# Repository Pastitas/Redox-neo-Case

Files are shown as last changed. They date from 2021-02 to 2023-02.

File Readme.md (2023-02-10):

# Redox-neo keyboard Case
Redox-neo is just a case for the redox keyboard (both wireless and wired versions) based on looks and getting 'thicness' down as much as possible,  while still being 3d printable.
I also wanted to save space by using the original pcb mounting holes.
note that this should be compatible with wireless rev2 since the hole that
changes is non-essential for the case and the other 3 will work just fine

## Pics

redox_w

redox_w

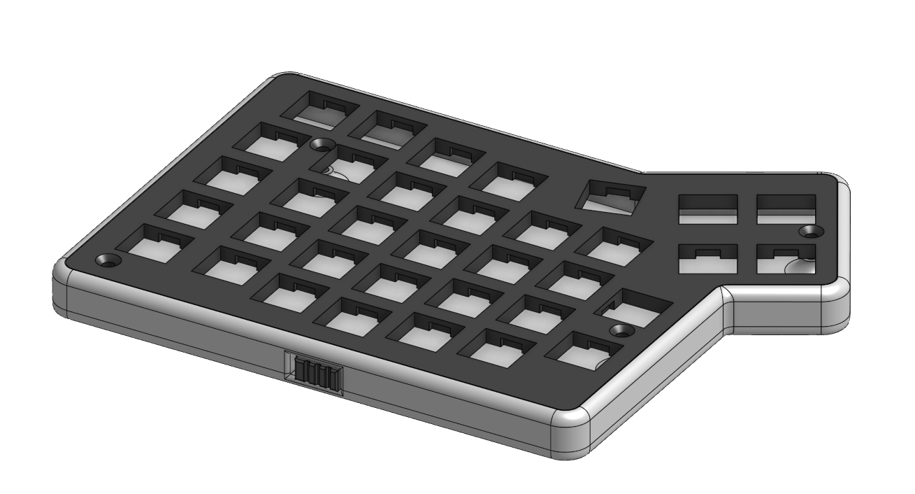
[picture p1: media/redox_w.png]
redox_w


## Usage guide
There is a calibration tester file (inside the switch_plate_tester folder) you can print with the following tolerances for the switches:
1 0.20 mm
2 0.16 mm
3 0.12 mm
4 0.08 mm

After testing your switches there you can then choose any tolerance on the stls, it's the last number in the name of the top parts

If that's not enough for your printer or want to make any changes just fork this, all files have their asociated step files WITHOUT ANY OFFSETS.

There are also testers in step format form the holes of the microcontroller and trs jacks (so you can test fit before printing and wasting plastic and time) and the alignment of the switches in the redox_w

## Screws

M3x10 screws x8 should work well without inserts.

2.5 inserts also work, but you might have to drill a bit of the holes for them to fit in (drill in reverse so you dont overdrill)

 ## Wrist Rest
by user [idaho777](https://github.com/idaho777)

I've created a set of wrist rests that maintain both dimensions and style of the original case.  These have a curved slope from the top to the bottom since that's the feeling i'm used to.

The images below are printed with layer height 0.28mm and 10% infill.
Top View            |  Side View
:-------------------------:|:-------------------------:
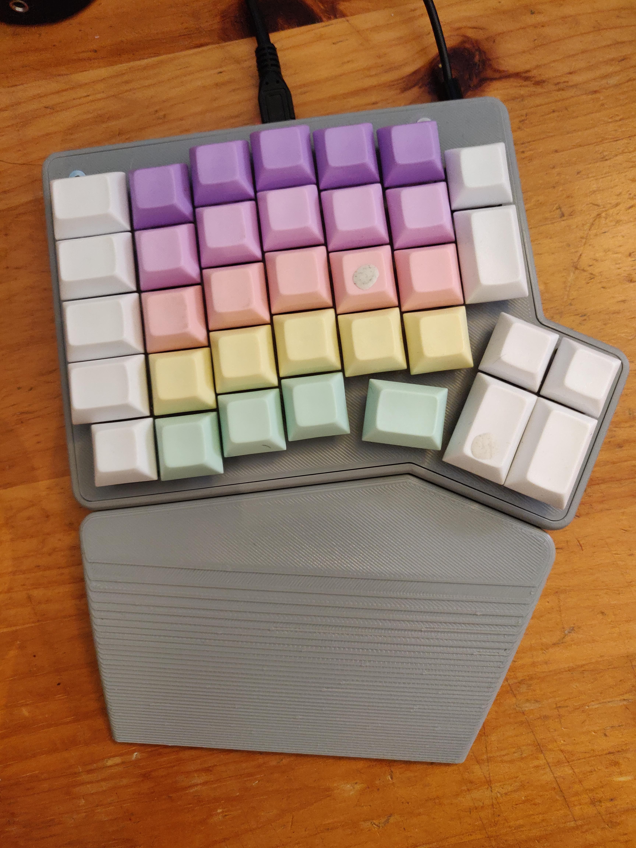
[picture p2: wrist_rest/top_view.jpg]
top view
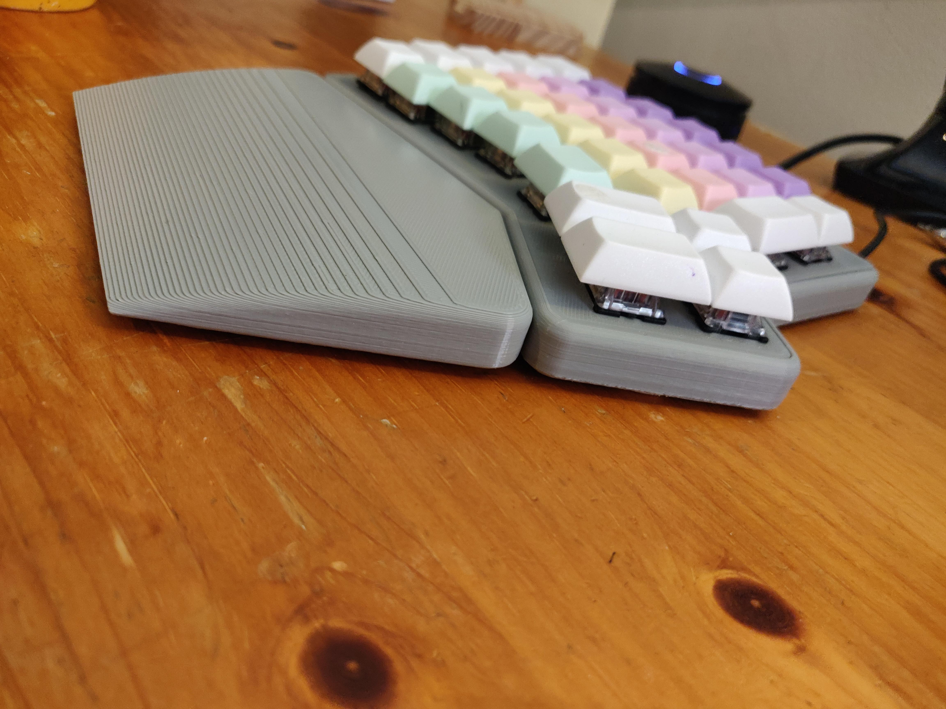
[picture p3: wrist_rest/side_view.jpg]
side view
 |

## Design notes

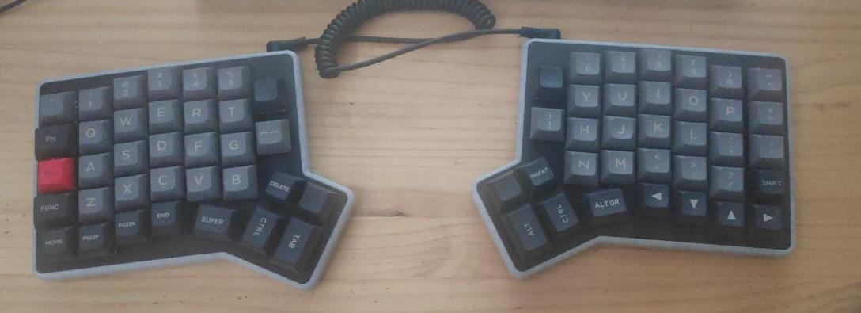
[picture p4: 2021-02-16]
media/ redox_rev1.0.jpg

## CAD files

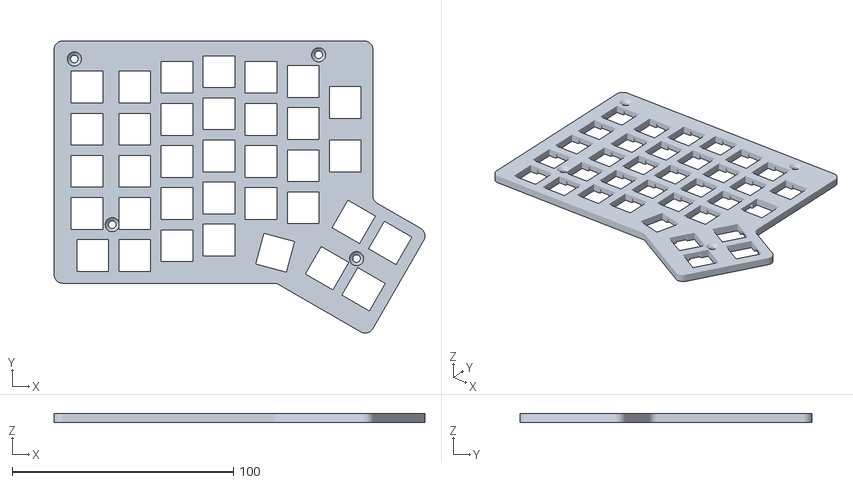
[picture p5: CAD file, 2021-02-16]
redox_rev1.0/Redox_neo_rev1.0-Top-Left_0.2.stl
167.8 x 132.2 x 4.00

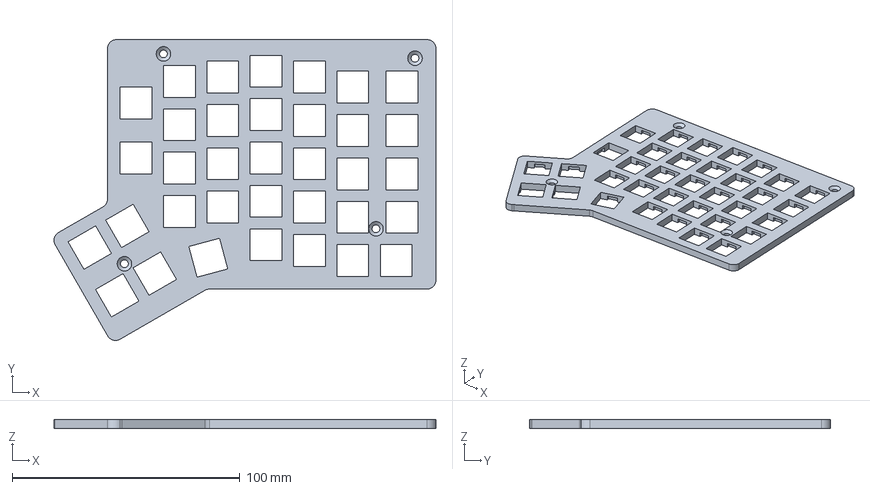
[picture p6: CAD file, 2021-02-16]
redox_rev1.0/step files/Redox_neo_rev1.0-Top-Right.step
167.8 x 132.1 x 4.00 mm

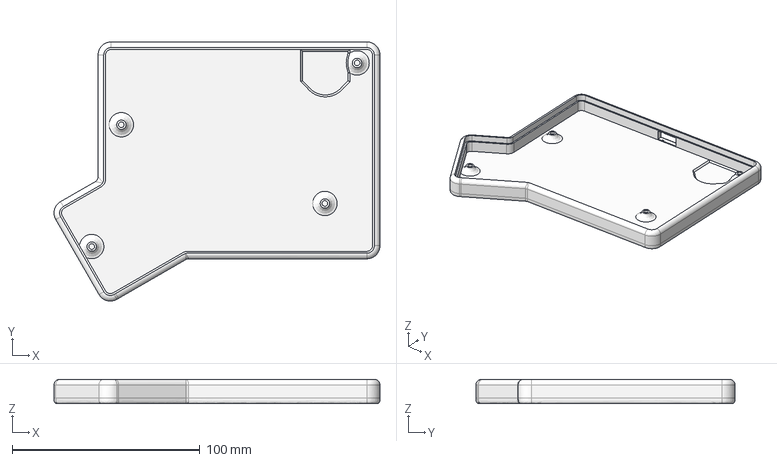
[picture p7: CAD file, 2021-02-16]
redox_w/step files/Redox_neo_w-Bottom-Right.step
173.8 x 138.1 x 13.0 mm

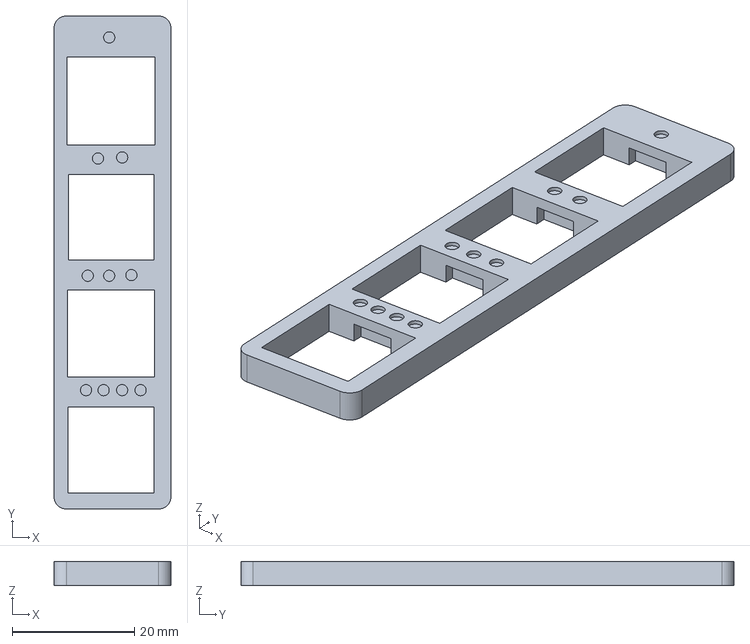
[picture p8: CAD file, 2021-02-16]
switch_plate_tester/Switch_plate_tester.step
19.1 x 80.7 x 4.00 mm

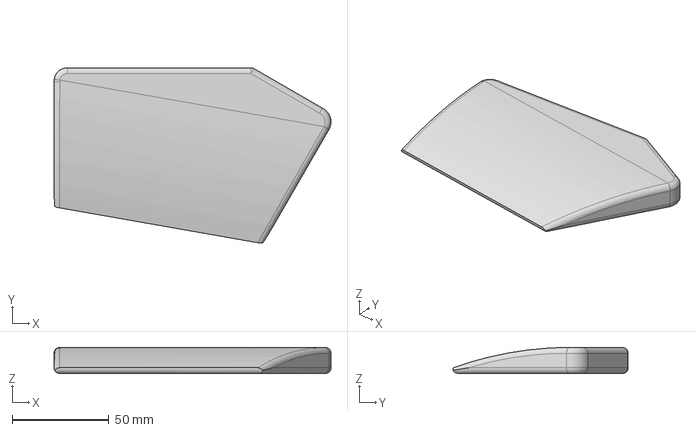
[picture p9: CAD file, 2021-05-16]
wrist_rest/Step/redox_wrist_left.step
143.4 x 90.8 x 13.5 mm

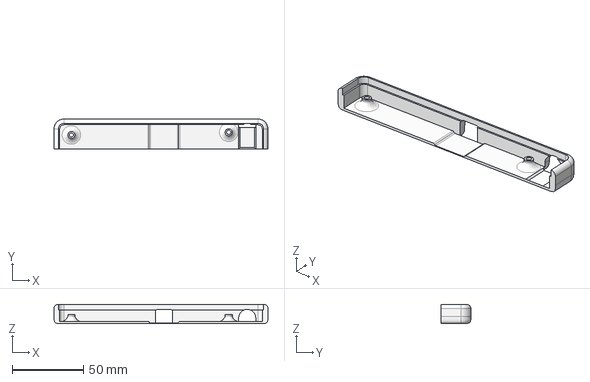
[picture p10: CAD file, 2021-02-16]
redox_rev1.0/step files/Redox_neo_rev1.0_tester-Bottom-Left-test.step
150.3 x 21.0 x 13.5 mm

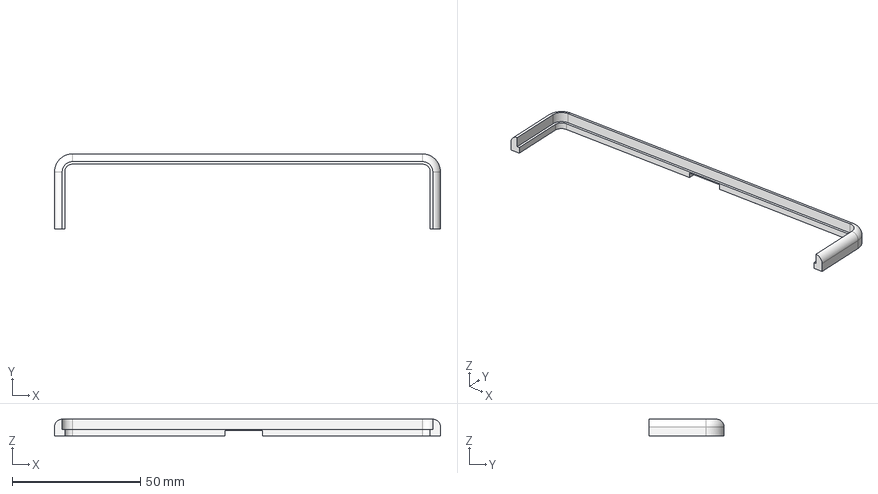
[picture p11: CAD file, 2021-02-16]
redox_w/step files/Redox_neo_w_tester - Bottom Right.step
150.3 x 29.3 x 6.50 mm

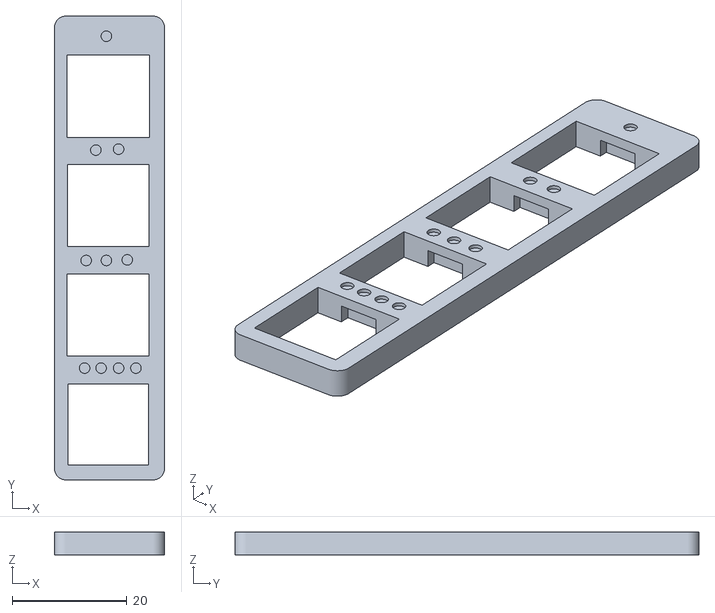
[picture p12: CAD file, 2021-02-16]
switch_plate_tester/Switch_plate_tester0.08-0.12-0.16-0.20.stl
19.1 x 80.7 x 4.00

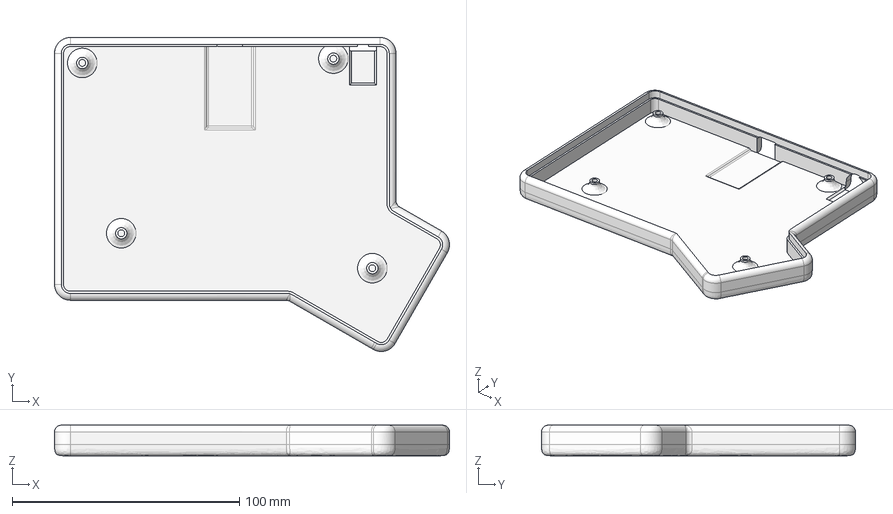
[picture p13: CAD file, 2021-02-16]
redox_rev1.0/step files/Redox_neo_rev1.0-Bottom-Left.step
173.8 x 138.1 x 13.5 mm

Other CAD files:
redox_w/Redox_neo_w-Top-Right_0.16.stl
redox_rev1.0/Redox_neo_rev1.0-Top-Right_0.2.stl
redox_w/Redox_neo_w-Top-Right_0.12.stl
wrist_rest/Step/redox_wrist_right.step
redox_rev1.0/Redox_neo_rev1.0-Top-Left_0.16.stl
redox_w/Redox_neo_w-Top-Left_0.08.stl
redox_w/step files/Redox_neo_w Bottom-Left.step
redox_rev1.0/Redox_neo_rev1.0-Top-Right_0.16.stl
redox_rev1.0/step files/Redox_neo_rev1.0-Top-Left.step
redox_rev1.0/Redox_neo_rev1.0-Top-Left_0.08.stl
redox_rev1.0/Redox_neo_rev1.0-Top-Left_0.12.stl
redox_rev1.0/Redox_neo_rev1.0-Top-Right_0.08.stl
redox_rev1.0/Redox_neo_rev1.0-Top-Right_0.12.stl
redox_rev1.0/step files/Redox_neo_rev1.0-Bottom-Right.step
redox_rev1.0/step files/Redox_neo_rev1.0_tester-Bottom-Right-test.step
redox_w/Redox_neo_w-Switch-Left.stl
redox_w/Redox_neo_w-Switch-Right.stl
redox_w/Redox_neo_w-Top-Left_0.12.stl
redox_w/Redox_neo_w-Top-Left_0.16.stl
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

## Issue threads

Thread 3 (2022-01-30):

[Question] Does this case include clearance for the microcontroller?

JamesYeoman, 2022-01-30:
I want to be able to use standard microcontroller standoffs, and the falbatech case has enough clearance for that, but no model for 3d printing the design. Does this case have enough clearance? Or do I need to keep looking?

Pastitas, 2022-03-01:
I don't think so, this design was done so that minimum height could be achieved, so it uses the sockets

JamesYeoman, 2022-03-03:
Ok, thanks for the response

Closed 2022-03-03.

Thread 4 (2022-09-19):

Screw Types

enra64, 2022-09-19:
Hi! Looks like an awesome design!

Could you tell me what kind of screws you used for mounting? Also, did you used heated inserts?

Thank you!

enra64, 2022-09-19:
So, from fit testing it's M3 without heated inserts. Haven't found the length yet

enra64, 2022-09-21:
10mm works :)

Closed 2022-09-21.

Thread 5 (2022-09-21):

Type of screw/fastener missing from documentation.

cmcgrew, 2022-09-21:
Wondering what type of screw/fastener is used to fasten the top and bottom pieces together. Please let me know. I'd be happy to create a PR and add it to the docs.

Closed 2022-09-29.

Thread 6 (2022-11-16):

Labeling of tolerances on test

evidenz, 2022-11-16:
Perhaps I do not get it but how is the tolerance defined for the test?

There are circles that increase in number (from top to bottom it is 1,2,3 and 4). Does that mean that the 4 circles indicate that it is the biggest tolerance of 0.20 mm? Or is it the other way around? From testing it actually feels the other way around (with the 4 circles my switches have the snuggest fitting?

Cheers and thanks for the help!

Pastitas, 2022-11-16:
Yes, I notice now that it's kind of counterintuitive, I've adjusted the instructions in the readme. But yeah, you're right, the higher, the tighter the tolerance

Pastitas, 2022-11-16:
Fixed 7ecffc8

Closed 2022-11-16.

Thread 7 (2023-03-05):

Provide source / project files for case

a-kempka, 2023-03-05:
Thank you for providing such a great case for the redox keyboard. It's one of the most aesthetic and comfortable ones out there.

I tried to use the redox pcb with a kb2040 (which is slightly thicker) and the case doesn't fit. Furthermore peel-a-way sockets are nearly impossible to source for me.

Would you please provide the project files (openscad, fusion 360, freecad - any is ok) for the rev1.0 case? I need to have approximately 2 mm more clearance below the pcb to accomodate for the thicher kb2040 and a slightly thicker socket. Plus the TRRS port is a bit off on the PCB. Fixing these things would be easiest with a project file.

Slicing and patching the STEP files is quite a pain although I appreciate that you included those over STL files.

Pastitas, 2023-03-08:
I'm afraid I've not saved the project files anywhere, it was done all in freecad but since it's kinda unreliable at times I thought the step files would be a better way of storing the info.

The offset trrs was on purpose as for the revision of the pcb that I got (the first one i think) the trrs socket was offset differently in both halves.

I'm sorry to not be able to provide the proyect files however if you do make any changes and want to fork or merge your  modifications with this repo feel free to open a pull request.

Thanks for the kind words and using the case.

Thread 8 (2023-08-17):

Reset Button

tarnis, 2023-08-17:
Would you mind adding a hole for the reset button to the bottom?

Was also wondering before I print, is there room in here for LED's?  It's slimmer than the original.

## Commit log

2021-02-16 added all rev1.0 parts and offset stls
    [Neodox_rev1.0-Top-Left_0.12.stl, Neodox_rev1.0-Top-Left_0.8.stl, Neodox_rev1.0-Top-Right_0.12.stl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]
2021-02-16 added all rev1.0 parts and offset stls for good this time
    [Neodox_rev1.0-Bottom-Left.step, Neodox_rev1.0-Bottom-Right.step, Neodox_rev1.0-Top-Left.step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]
2021-02-16 added all redox_w parts and offset stls for good this time
    [Neodox_w Bottom-Left.step, Neodox_w-Bottom-Right.step, Neodox_w-Switch-Left.step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]
2021-02-16 fixed incorrect tolerance in name
    [Neodox_rev1.0-Top-Left_0.08.stl, Neodox_rev1.0-Top-Right_0.08.stl]
2021-05-14 designed curved/slanted wrist rests for Neodox Redox keyboard case
    [Neodox_rev1.0-left-wrist.stl, Neodox_rev1.0-right-wrist.stl]
2021-05-16 Added step files
    [Neodox_rev1.0-left-wrist.stl, Neodox_rev1.0-right-wrist.stl, redox_wrist_left.step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]
2023-02-10 change name everywhere
    [Redox_neo_rev1.0-Bottom-Left.step, Redox_neo_rev1.0-Bottom-Right.step, Redox_neo_rev1.0-Top-Left.step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]
